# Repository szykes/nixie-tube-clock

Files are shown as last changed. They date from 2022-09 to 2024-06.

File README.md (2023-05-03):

# nixie-tube-clock

ezgif com-gif-maker-3





At first I declared my requirements for my ideal clock. Here are the requirements:
  * No touch working: there shall not be any button or something like that but the clock shall follow daylight saving time or it shall be set after a power outage.
  * Dust resistant: the dust shall not affect the visibility of clock and it shall not be on the PCB and parts.
  * Beautiful: The clock shall have maximum 2 dominant colors (PCB, parts and enclosure).
  
To implement "no touch working" I used a Wifi module to query the accureate time from my home server.
For "dust resistant" requirement I put the clock in a plastic enclosure to procect the core of clock.
"Beautiful" is implemented by selecting white PCB and mostly black parts.

## Docker

```
docker build -t time-server:v1.0 .
docker-compose up -d
```

## Hardware

### Measurements
  * Cathode voltage: 178 V
  * Cathode current: ~800 uA
  * Glim lamp current: ~250 uA
  * Total current: ~220 mA @ 12,2 V without WiFi.
  
### Known issues
  * RBG LED flahes at power-on. The gate of MOSFET of LEDs require a pull-down resistor.
  * PCB design of tube is wrong. The place drawing of tube is mirrored; therefore, digit 7 is digit 4 in real.

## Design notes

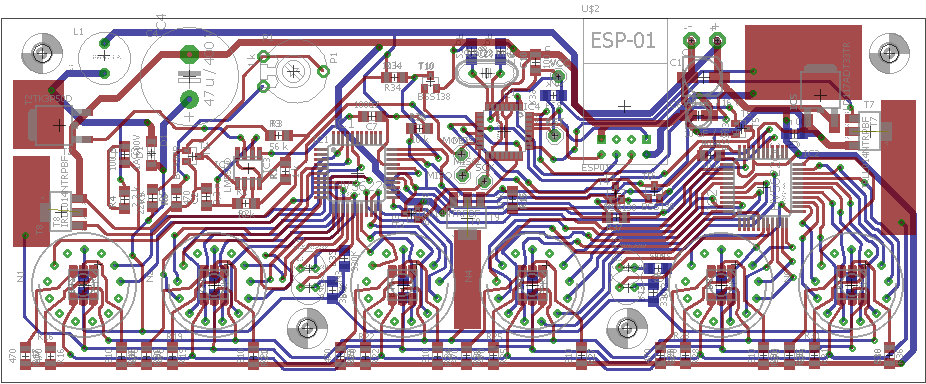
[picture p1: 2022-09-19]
eagle/nixie-tube-clock-pcb.png

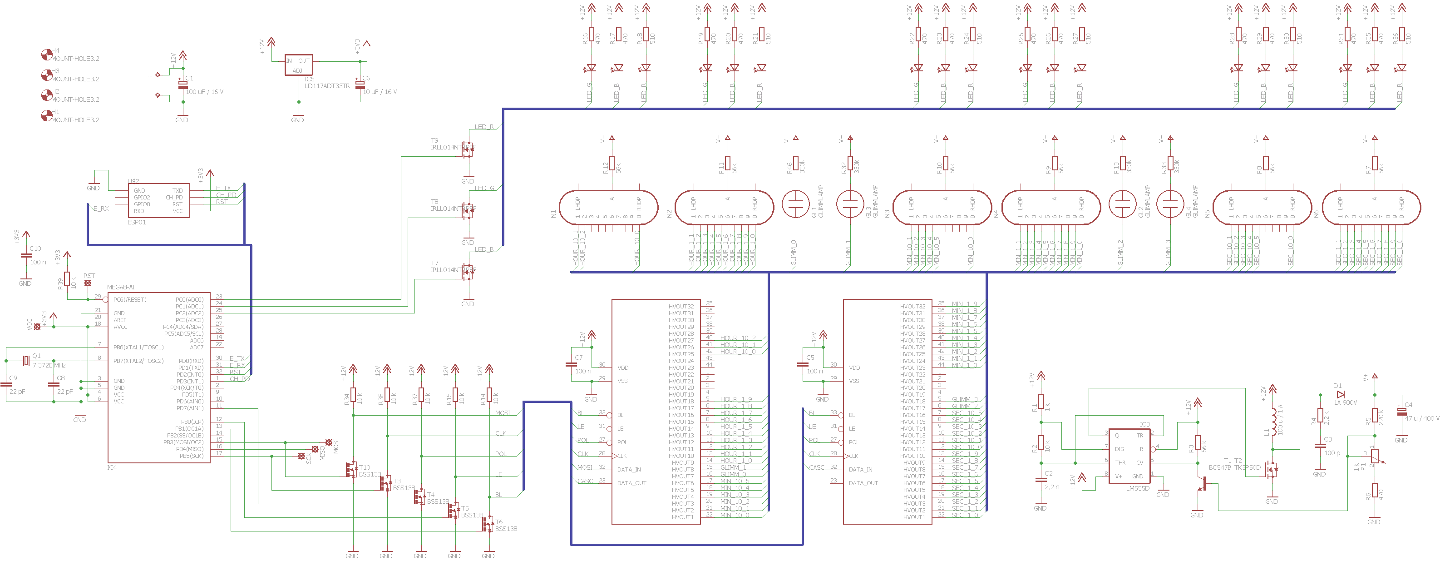
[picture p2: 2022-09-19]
eagle/nixie-tube-clock-sch.png

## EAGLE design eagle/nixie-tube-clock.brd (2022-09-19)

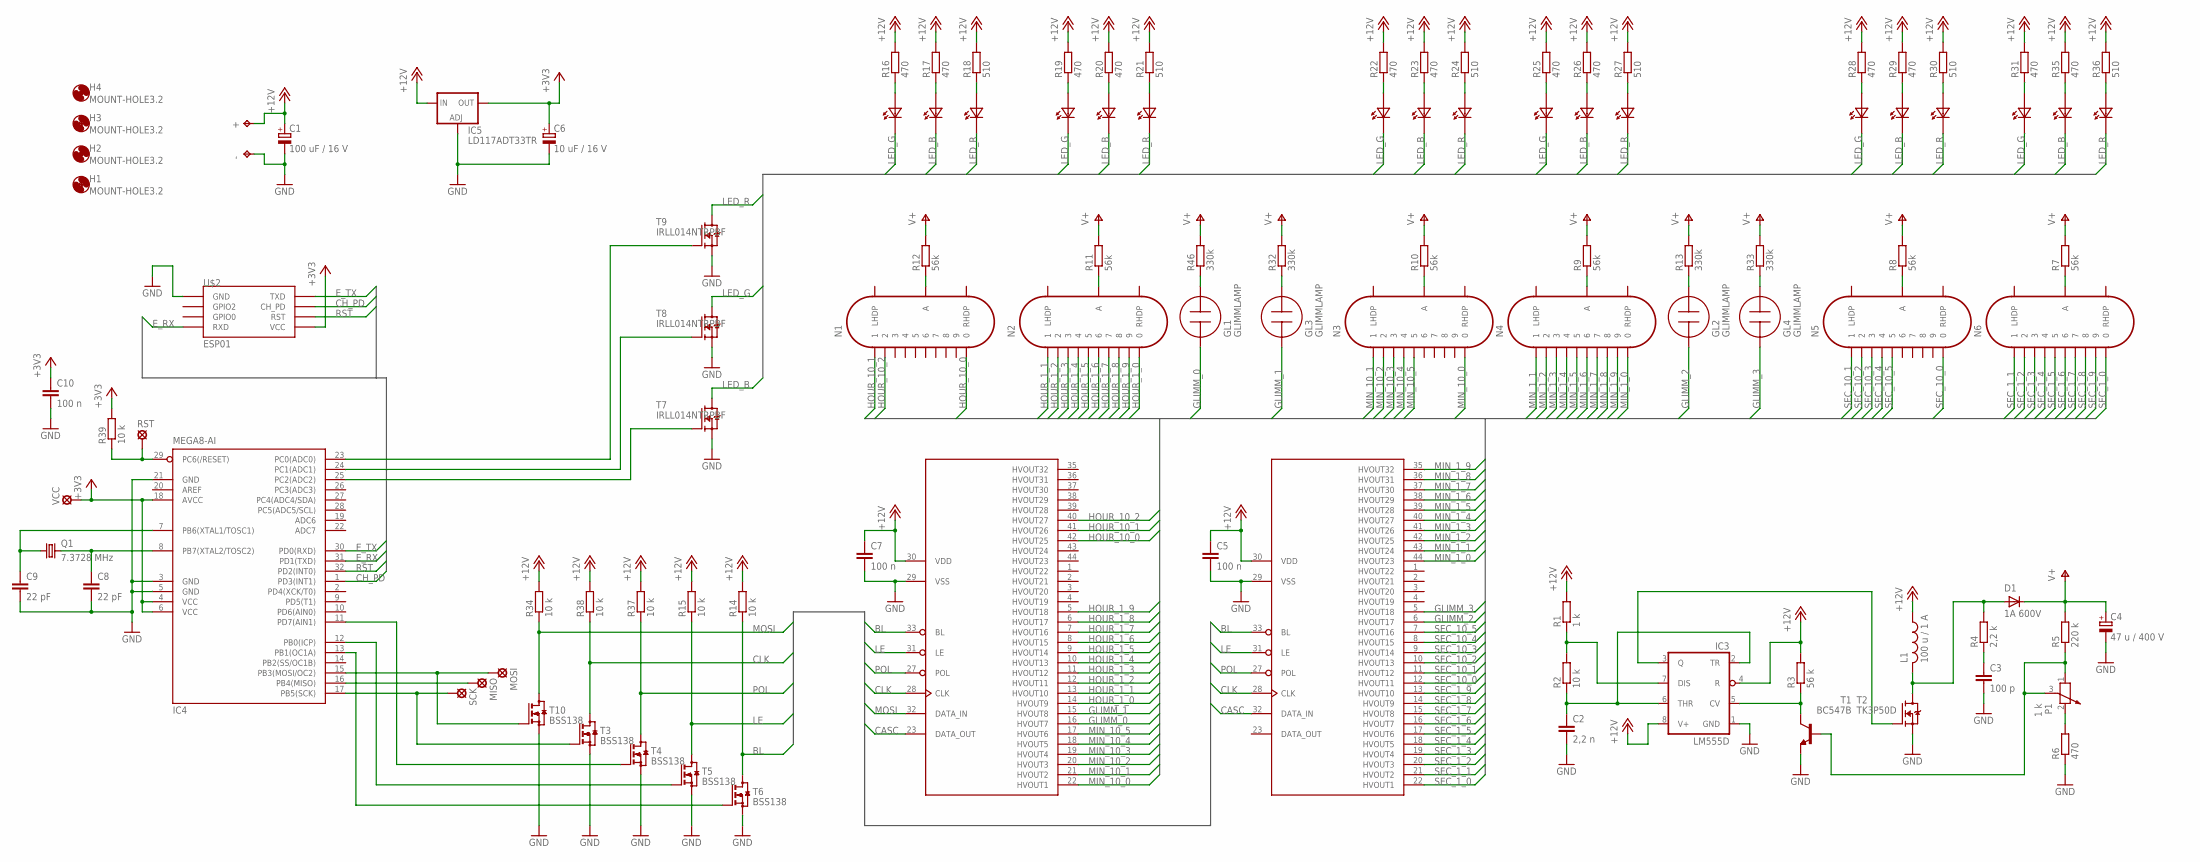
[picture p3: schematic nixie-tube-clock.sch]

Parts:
+: +; P1-17
-: -; P1-17
C1: 100 uF / 16 V; 153CLV-0605
C2: 2,2 n; C1206
C3: 100 p; C1206
C4: 47 u / 400 V; E7,5-16
C5, C7, C10: 100 n; C1206
C6: 10 uF / 16 V; 153CLV-0405
C8, C9: 22 pF; C1206
D1: 1A 600V; SMA-DO214AC
GL1, GL2, GL3, GL4: GLIMMLAMP
H1, H2, H3, H4: MOUNT-HOLE3.2; 3,2
IC1, IC2: HV5622QC; PQFP44
IC3: LM555D; SO08
IC4: MEGA8-AI; TQFP32-08
IC5: LD117ADT33TR; DPACK
L1: 100 u / 1 A; L_V_8.7X12_RM5.0
MISO: MISO; SE11
MOSI: MOSI; SE11
N1, N2, N3, N4, N5, N6: IN-14
P1: 1 k; PT-10
Q1: 7.3728 MHz; HC49/S
R1: 1 k; R1206
R2, R14, R15, R34, R37, R38, R39: 10 k; R1206
R3: 56 k; R1206
R4: 2,2 k; R1206
R5: 220 k; R1206
R6, R16, R17, R19, R20, R22, R23, R25, R26, R28, R29, R31, R35: 470; R1206
R7, R8, R9, R10, R11, R12: 56k; R1206
R13, R32, R33, R46: 330k; R1206
R18, R21, R24, R27, R30, R36: 510; R1206
RST: RST; SE11
SCK: SCK; SE11
T1: BC547B; SOT23-BEC
T2: TK3P50D; TO252
T3, T4, T5, T6, T10: BSS138; SOT23
T7, T8, T9: IRLL014NTRPBF; SOT223
U$1, U$3, U$4, U$5, U$6, U$7: OF-SMD5060RGB
U$2: ESP01
VCC: VCC; SE11

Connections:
+3V3: C6.+, C10.1, IC4.4 (VCC), IC4.6 (VCC), IC4.18 (AVCC), IC5.4 (OUT), R39.2, U$2.VCC, VCC.MP
+12V: +.TP, C1.+, C5.1, C7.1, IC1.30 (VDD), IC2.30 (VDD), IC3.4 (R), IC3.8 (V+), IC5.3 (IN), L1.P$1 (1), R1.2, R3.2, R14.2, R15.2, R16.2, R17.2, R18.2, R19.2, R20.2, R21.2, R22.2, R23.2, R24.2, R25.2, R26.2, R27.2, R28.2, R29.2, R30.2, R31.2, R34.2, R35.2, R36.2, R37.2, R38.2
BL: IC1.33 (BL), IC2.33 (BL), R14.1, T6.3 (D)
CASC: IC1.23 (DATA_OUT), IC2.32 (DATA_IN)
CH_PD: IC4.1 (PD3(INT1)), U$2.CH_PD
CLK: IC1.28 (CLK), IC2.28 (CLK), R38.1, T3.3 (D)
E_RX: IC4.31 (PD1(TXD)), U$2.RX (RXD)
E_TX: IC4.30 (PD0(RXD)), U$2.TX (TXD)
GLIMM_0: GL1.C, IC1.16 (HVOUT7)
GLIMM_1: GL3.C, IC1.15 (HVOUT8)
GLIMM_2: GL2.C, IC2.6 (HVOUT17)
GLIMM_3: GL4.C, IC2.5 (HVOUT18)
GND: -.TP, C1.-, C2.2, C3.2, C4.-, C5.2, C6.-, C7.2, C8.2, C9.2, C10.2, IC1.29 (VSS), IC2.29 (VSS), IC3.1 (GND), IC4.3 (GND), IC4.5 (GND), IC4.21 (GND), IC5.1 (ADJ), R6.1, T1.E, T2.2 (S), T3.2 (S), T4.2 (S), T5.2 (S), T6.2 (S), T7.3 (S), T8.3 (S), T9.3 (S), T10.2 (S), U$2.GND
HOUR_1_0: IC1.14 (HVOUT9), N2.0
HOUR_1_1: IC1.13 (HVOUT10), N2.1
HOUR_1_2: IC1.12 (HVOUT11), N2.2
HOUR_1_3: IC1.11 (HVOUT12), N2.3
HOUR_1_4: IC1.10 (HVOUT13), N2.4
HOUR_1_5: IC1.9 (HVOUT14), N2.5
HOUR_1_6: IC1.8 (HVOUT15), N2.6
HOUR_1_7: IC1.7 (HVOUT16), N2.7
HOUR_1_8: IC1.6 (HVOUT17), N2.8
HOUR_1_9: IC1.5 (HVOUT18), N2.9
HOUR_10_0: IC1.42 (HVOUT25), N1.0
HOUR_10_1: IC1.41 (HVOUT26), N1.1
HOUR_10_2: IC1.40 (HVOUT27), N1.2
LE: IC1.31 (LE), IC2.31 (LE), R15.1, T5.3 (D)
LED_B: T7.2 (D), T7.4 (D), U$1.B_CATH (CATH), U$3.B_CATH (CATH), U$4.B_CATH (CATH), U$5.B_CATH (CATH), U$6.B_CATH (CATH), U$7.B_CATH (CATH)
LED_D0: IC4.23 (PC0(ADC0)), T9.1 (G)
LED_D1: IC4.24 (PC1(ADC1)), T8.1 (G)
LED_D2: IC4.25 (PC2(ADC2)), T7.1 (G)
LED_G: T8.2 (D), T8.4 (D), U$1.G_CATH (CATH), U$3.G_CATH (CATH), U$4.G_CATH (CATH), U$5.G_CATH (CATH), U$6.G_CATH (CATH), U$7.G_CATH (CATH)
LED_R: T9.2 (D), T9.4 (D), U$1.R_CATH (CATH), U$3.R_CATH (CATH), U$4.R_CATH (CATH), U$5.R_CATH (CATH), U$6.R_CATH (CATH), U$7.R_CATH (CATH)
MIN_1_0: IC2.44 (HVOUT23), N4.0
MIN_1_1: IC2.43 (HVOUT24), N4.1
MIN_1_2: IC2.42 (HVOUT25), N4.2
MIN_1_3: IC2.41 (HVOUT26), N4.3
MIN_1_4: IC2.40 (HVOUT27), N4.4
MIN_1_5: IC2.39 (HVOUT28), N4.5
MIN_1_6: IC2.38 (HVOUT29), N4.6
MIN_1_7: IC2.37 (HVOUT30), N4.7
MIN_1_8: IC2.36 (HVOUT31), N4.8
MIN_1_9: IC2.35 (HVOUT32), N4.9
MIN_10_0: IC1.22 (HVOUT1), N3.0
MIN_10_1: IC1.21 (HVOUT2), N3.1
MIN_10_2: IC1.20 (HVOUT3), N3.2
MIN_10_3: IC1.19 (HVOUT4), N3.3
MIN_10_4: IC1.18 (HVOUT5), N3.4
MIN_10_5: IC1.17 (HVOUT6), N3.5
MOSI: IC1.32 (DATA_IN), R34.1, T10.3 (D)
unnamed: IC4.29 (PC6(/RESET)), R39.1, RST.MP
unnamed: IC3.7 (DIS), R1.1, R2.2
unnamed: IC3.5 (CV), R3.1, T1.C
unnamed: C2.1, IC3.2 (TR), IC3.6 (THR), R2.1
unnamed: IC3.3 (Q), T2.1 (G)
unnamed: D1.A, L1.P$2 (2), R4.2, T2.3 (D)
unnamed: P1.1, P1.3, R5.1, T1.B
unnamed: C3.1, R4.1
unnamed: P1.2, R6.2
unnamed: N1.A, R12.1
unnamed: N2.A, R11.1
unnamed: N3.A, R10.1
unnamed: N4.A, R9.1
unnamed: N5.A, R8.1
unnamed: N6.A, R7.1
unnamed: IC4.16 (PB4(MISO)), MISO.MP
unnamed: GL2.A, R13.1
unnamed: IC4.13 (PB1(OC1A)), T6.1 (G)
unnamed: R16.1, U$1.G_ANODE (ANODE)
unnamed: R17.1, U$1.B_ANODE (ANODE)
unnamed: R18.1, U$1.R_ANODE (ANODE)
unnamed: C8.1, IC4.8 (PB7(XTAL2/TOSC2)), Q1.2
unnamed: GL3.A, R32.1
unnamed: R19.1, U$3.G_ANODE (ANODE)
unnamed: R20.1, U$3.B_ANODE (ANODE)
unnamed: R21.1, U$3.R_ANODE (ANODE)
unnamed: IC4.12 (PB0(ICP)), T5.1 (G)
unnamed: GL4.A, R33.1
unnamed: C9.1, IC4.7 (PB6(XTAL1/TOSC1)), Q1.1
unnamed: R22.1, U$4.G_ANODE (ANODE)
unnamed: R23.1, U$4.B_ANODE (ANODE)
unnamed: R24.1, U$4.R_ANODE (ANODE)
unnamed: IC4.17 (PB5(SCK)), SCK.MP, T3.1 (G)
unnamed: R25.1, U$5.G_ANODE (ANODE)
unnamed: R26.1, U$5.B_ANODE (ANODE)
unnamed: R27.1, U$5.R_ANODE (ANODE)
unnamed: IC4.15 (PB3(MOSI/OC2)), MOSI.MP, T10.1 (G)
unnamed: IC4.11 (PD7(AIN1)), T4.1 (G)
unnamed: R28.1, U$6.G_ANODE (ANODE)
unnamed: R29.1, U$6.B_ANODE (ANODE)
unnamed: R30.1, U$6.R_ANODE (ANODE)
unnamed: R31.1, U$7.G_ANODE (ANODE)
unnamed: R35.1, U$7.B_ANODE (ANODE)
unnamed: R36.1, U$7.R_ANODE (ANODE)
unnamed: GL1.A, R46.1
POL: IC1.27 (POL), IC2.27 (POL), R37.1, T4.3 (D)
RST: IC4.32 (PD2(INT0)), U$2.RST
SEC_1_0: IC2.22 (HVOUT1), N6.0
SEC_1_1: IC2.21 (HVOUT2), N6.1
SEC_1_2: IC2.20 (HVOUT3), N6.2
SEC_1_3: IC2.19 (HVOUT4), N6.3
SEC_1_4: IC2.18 (HVOUT5), N6.4
SEC_1_5: IC2.17 (HVOUT6), N6.5
SEC_1_6: IC2.16 (HVOUT7), N6.6
SEC_1_7: IC2.15 (HVOUT8), N6.7
SEC_1_8: IC2.14 (HVOUT9), N6.8
SEC_1_9: IC2.13 (HVOUT10), N6.9
SEC_10_0: IC2.12 (HVOUT11), N5.0
SEC_10_1: IC2.11 (HVOUT12), N5.1
SEC_10_2: IC2.10 (HVOUT13), N5.2
SEC_10_3: IC2.9 (HVOUT14), N5.3
SEC_10_4: IC2.8 (HVOUT15), N5.4
SEC_10_5: IC2.7 (HVOUT16), N5.5
V+: C4.+, D1.K (C), R5.2, R7.2, R8.2, R9.2, R10.2, R11.2, R12.2, R13.2, R32.2, R33.2, R46.2

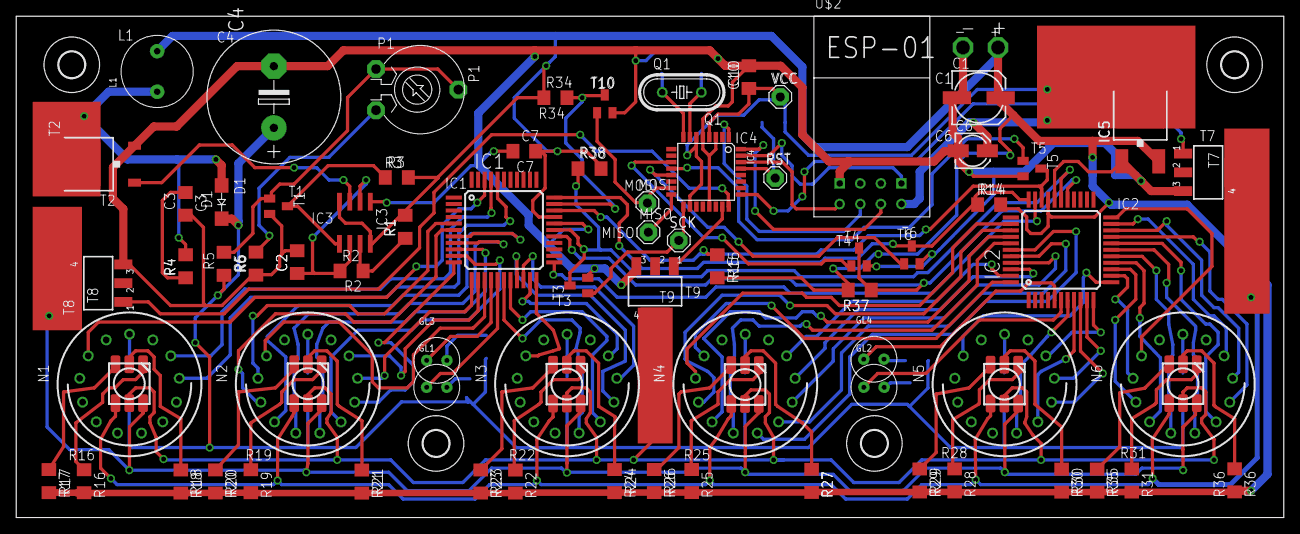
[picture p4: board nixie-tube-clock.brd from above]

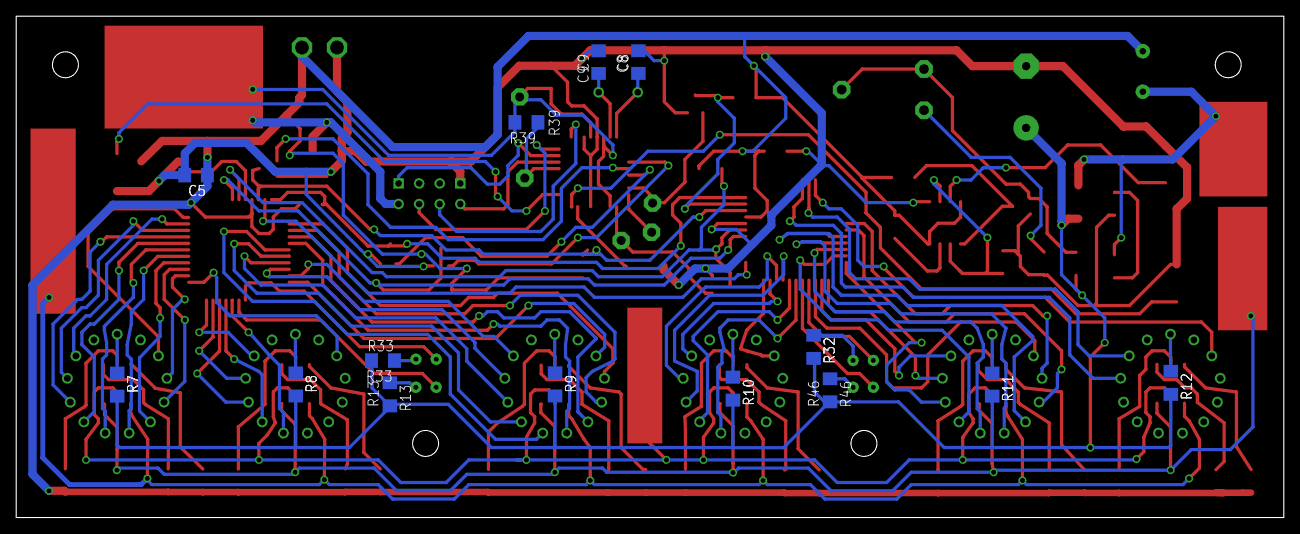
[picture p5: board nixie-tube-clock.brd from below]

Board: 2 copper layers, 156.4 x 61.9 mm, 97 parts (14 on the bottom side), 114 nets.

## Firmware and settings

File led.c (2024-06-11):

#include "led.h"

#include <stdbool.h>
#include <stdint.h>
#include <math.h>

#include "avr.h"
#include "wifi.h"
#include "clock.h"

#define MAX_CNT 240 // 28 800 Hz to 120 Hz

#define TIMER_INIT_CNT 0xFF

#define HHM_TO_SECS(hour_10, hour_1, min_10) ( \
    (hour_10) * 10 * 3600 +				\
    (hour_1) * 3600 +					\
    (min_10) * 10 * 60)

#define BRIGHT_PERIOD_IN_SECS ( \
  HHM_TO_SECS(MAX_HOUR_10, MAX_HOUR_1, MAX_MIN_10) - \
  HHM_TO_SECS(MIN_HOUR_10, MIN_HOUR_1, MIN_MIN_10))

#define SEVENTH_OF_BRIGHT_PERIOD_IN_SECS (BRIGHT_PERIOD_IN_SECS / (float) 7)

#define RATIO_MODIFIER 10

static volatile bool is_calculate = false;

static volatile uint8_t red_ratio = 0;
static volatile uint8_t green_ratio = 0;
static volatile uint8_t blue_ratio = 0;

static uint32_t get_time_in_secs(void) {
  const time_st *time = clock_get_time();
  uint32_t secs = 0;
  secs += time->hour_10 * 10ul * 3600ul;
  secs += time->hour_1 * 3600ul;
  secs += time->min_10 * 10ul * 60ul;
  secs += time->min_1 * 60ul;
  secs += time->sec_10 * 10ul;
  secs += time->sec_1;
  return secs;
}

static uint8_t increasing_ratio(uint32_t base) {
  uint16_t ratio = lrintf(base / (SEVENTH_OF_BRIGHT_PERIOD_IN_SECS / (float) (MAX_CNT + RATIO_MODIFIER)));
  return (ratio > MAX_CNT ? MAX_CNT : ratio);
}

static uint8_t decreasing_ratio(uint32_t base) {
  uint16_t ratio = lrintf(base / (SEVENTH_OF_BRIGHT_PERIOD_IN_SECS / (float) (MAX_CNT + RATIO_MODIFIER)));
  return MAX_CNT - (ratio > MAX_CNT ? MAX_CNT : ratio);
}

unsigned char led_isr(void) {
  static uint8_t cnt = 0;

  if (cnt >= MAX_CNT) {
    cnt = 0;
    clock_timer_interrupt();

    if (red_ratio != 0) {
      gpio_led_red_set();
    }
    if (green_ratio != 0) {
      gpio_led_green_set();
    }
    if (blue_ratio != 0) {
      gpio_led_blue_set();
    }
  }

  if (cnt >= red_ratio) {
    gpio_led_red_reset();
  }

  if (cnt >= green_ratio) {
    gpio_led_green_reset();
  }

  if (cnt >= blue_ratio) {
    gpio_led_blue_reset();
  }

  cnt++;

  return TIMER_INIT_CNT;
}

void led_init(void) {
  timer0_init(TIMER_INIT_CNT);
}

void led_timer_interrupt(void) {
  is_calculate = true;
}

void led_main(void) {
  if (is_calculate) {
    is_calculate = false;

    int64_t secs = get_time_in_secs() - HHM_TO_SECS(MIN_HOUR_10, MIN_HOUR_1, MIN_MIN_10);
    if (secs < 0) {
      secs = 0;
    }

    uint32_t mod = 0;
    if (secs >= 43208) {
      mod = 3;
    } else if (secs >= 28807) {
      mod = 2;
    } else if (secs >= 14403) {
      mod = 1;
    }

    uint32_t base = (secs + mod) % ((uint32_t) SEVENTH_OF_BRIGHT_PERIOD_IN_SECS + 1);

    if (secs > (7 * SEVENTH_OF_BRIGHT_PERIOD_IN_SECS) - 1) {
      red_ratio = 0;
      green_ratio = 0;
      blue_ratio = 0;
    } else if (secs > (6 * SEVENTH_OF_BRIGHT_PERIOD_IN_SECS) - 1) {
      red_ratio = 0;
      green_ratio = 0;
      blue_ratio = decreasing_ratio(base);
    } else if (secs > (5 * SEVENTH_OF_BRIGHT_PERIOD_IN_SECS)) {
      red_ratio = 0;
      green_ratio = decreasing_ratio(base);
      blue_ratio = MAX_CNT;
    } else if (secs > (4 * SEVENTH_OF_BRIGHT_PERIOD_IN_SECS) - 1) {
      red_ratio = 0;
      green_ratio = MAX_CNT;
      blue_ratio = increasing_ratio(base);
    } else if (secs > (3 * SEVENTH_OF_BRIGHT_PERIOD_IN_SECS)) {
      red_ratio = decreasing_ratio(base);
      green_ratio = MAX_CNT;
      blue_ratio = 0;
    } else if (secs > (2 * SEVENTH_OF_BRIGHT_PERIOD_IN_SECS) - 1) {
      red_ratio = MAX_CNT;
      green_ratio = increasing_ratio(base);
      blue_ratio = 0;
    } else if (secs > SEVENTH_OF_BRIGHT_PERIOD_IN_SECS) {
      red_ratio = MAX_CNT;
      green_ratio = 0;
      blue_ratio = decreasing_ratio(base);
    } else if (secs > 0) {
      red_ratio = increasing_ratio(base);
      green_ratio = 0;
      blue_ratio = increasing_ratio(base);
    } else {
      red_ratio = 0;
      green_ratio = 0;
      blue_ratio = 0;
    }
  }
}

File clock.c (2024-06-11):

#include "clock.h"

#include <stddef.h>
#include <string.h>
#include <stdbool.h>
#include <limits.h>

#include "avr.h"
#include "led.h"
#include "wifi.h"

/*
time_data[0]
7      | 6      | 5      | 4      | 3      | 2      | 1      | 0
M_1_2  | M_1_3  | M_1_4  | M_1_5  | M_1_6  | M_1_7  | M_1_8  | M_1_9

time_data[1]
7      | 6      | 5      | 4      | 3      | 2      | 1      | 0
M_1_0  | M_1_1  | NC     | NC     | NC     | NC     | GLIM_3 | GLIM_2

time_data[2]
7      | 6      | 5      | 4      | 3      | 2      | 1      | 0
S_10_5 | S_10_4 | S_10_3 | S_10_2 | S_10_0 | S_10_1 | S_1_2  | S_1_3

time_data[3]
7      | 6      | 5      | 4      | 3      | 2      | 1      | 0
S_1_4  | S_1_5  | S_1_6  | S_1_7  | S_1_8  | S_1_9  | S_1_0  | S_1_1

time_data[4]
7      | 6      | 5      | 4      | 3      | 2      | 1      | 0
NC     | NC     | NC     | NC     | NC     | H_10_2 | H_10_0 | H_10_1

time_data[5]
7      | 6      | 5      | 4      | 3      | 2      | 1      | 0
NC     | NC     | NC     | NC     | NC     | NC     | H_1_2  | H_1_3

time_data[6]
7      | 6      | 5      | 4      | 3      | 2      | 1      | 0
H_1_4  | H_1_5  | H_1_6  | H_1_7  | H_1_8  | H_1_9  | H_1_0  | H_1_1

time_data[7]
7      | 6      | 5      | 4      | 3      | 2      | 1      | 0
GLIM_1 | GLIM_0 | M_10_5 | M_10_4 | M_10_3 | M_10_2 | M_10_0 | M_10_1
 */


static time_st time_data;
static uint8_t time_raw_data[8];

static volatile bool increment_time = false;
static volatile bool resetting_glimm = false;

static void clear_time_raw_data(void) {
  memset(&time_raw_data, 0x00, sizeof(time_raw_data));
}

static void latch_enable(void) {
  gpio_latch_enable_reset();
  gpio_latch_enable_set();
}

static void reset_glimm(void) {
  time_raw_data[1] &= (uint8_t)~(3 << 0);
  time_raw_data[7] &= (uint8_t)~(3 << 6);
}

static void set_glimm(void) {
  time_raw_data[1] |= (3 << 0);
  time_raw_data[7] |= (3 << 6);
}

static void set_hour_10(uint8_t hour) {
  switch(hour) {
  case 0:
    time_raw_data[4] |= (1 << 1);
    break;
  case 1:
    time_raw_data[4] |= (1 << 0);
    break;
  case 2:
    time_raw_data[4] |= (1 << 2);
    break;
  default:
    break;
  }
}

static void set_hour_1(uint8_t hour) {
  switch(hour) {
  case 0:
    time_raw_data[6] |= (1 << 1);
    break;
  case 1:
    time_raw_data[6] |= (1 << 0);
    break;
  case 2:
    time_raw_data[5] |= (1 << 1);
    break;
  case 3:
    time_raw_data[5] |= (1 << 0);
    break;
  case 4:
    time_raw_data[6] |= (1 << 7);
    break;
  case 5:
    time_raw_data[6] |= (1 << 6);
    break;
  case 6:
    time_raw_data[6] |= (1 << 5);
    break;
  case 7:
    time_raw_data[6] |= (1 << 4);
    break;
  case 8:
    time_raw_data[6] |= (1 << 3);
    break;
  case 9:
    time_raw_data[6] |= (1 << 2);
    break;
  default:
    break;
  }
}

static void set_min_10(uint8_t min) {
  switch(min) {
  case 0:
    time_raw_data[7] |= (1 << 1);
    break;
  case 1:
    time_raw_data[7] |= (1 << 0);
    break;
  case 2:
  case 3:
  case 4:
  case 5:
    time_raw_data[7] |= (1 << min);
    break;
  default:
    break;
  }
}

static void set_min_1(uint8_t min) {
  switch(min) {
  case 0:
    time_raw_data[1] |= (1 << 7);
    break;
  case 1:
    time_raw_data[1] |= (1 << 6);
    break;
  case 2:
  case 3:
  case 4:
  case 5:
  case 6:
  case 7:
  case 8:
  case 9:
    time_raw_data[0] |= (1 << (9 - min));
    break;
  default:
    break;
  }
}

static void set_sec_10(uint8_t sec) {
  switch(sec) {
  case 0:
    time_raw_data[2] |= (1 << 3);
    break;
  case 1:
    time_raw_data[2] |= (1 << 2);
    break;
  case 2:
  case 3:
  case 4:
  case 5:
    time_raw_data[2] |= (1 << (sec + 2));
    break;
  default:
    break;
  }
}

static void set_sec_1(uint8_t sec) {
  switch(sec) {
  case 0:
    time_raw_data[3] |= (1 << 1);
    break;
  case 1:
    time_raw_data[3] |= (1 << 0);
    break;
  case 2:
    time_raw_data[2] |= (1 << 1);
    break;
  case 3:
    time_raw_data[2] |= (1 << 0);
    break;
  case 4:
    time_raw_data[3] |= (1 << 7);
    break;
  case 5:
    time_raw_data[3] |= (1 << 6);
    break;
  case 6:
    time_raw_data[3] |= (1 << 5);
    break;
  case 7:
    time_raw_data[3] |= (1 << 4);
    break;
  case 8:
    time_raw_data[3] |= (1 << 3);
    break;
  case 9:
    time_raw_data[3] |= (1 << 2);
    break;
  default:
    break;
  }
}

static bool is_dark_period(void) {
  return ((time_data.hour_10 == MAX_HOUR_10) && (time_data.hour_1 > MAX_HOUR_1)) ||
    ((time_data.hour_10 == MAX_HOUR_10) && (time_data.hour_1 == MAX_HOUR_1) && (time_data.min_10 >= MAX_MIN_10)) ||
    ((time_data.hour_10 == MIN_HOUR_10) && (time_data.hour_1 < MIN_HOUR_1)) ||
    ((time_data.hour_10 == MIN_HOUR_10) && (time_data.hour_1 == MIN_HOUR_1) && (time_data.min_10 < MIN_MIN_10));
}

static void calculate_time(void) {
  clear_time_raw_data();

  time_data.sec_1++;

  if (time_data.sec_1 >= 10) {
    time_data.sec_1 = 0;
    time_data.sec_10++;
  }

  if (time_data.sec_10 >= 6) {
    time_data.sec_10 = 0;
    time_data.min_1++;
  }

  if (time_data.min_1 >= 10) {
    time_data.min_1 = 0;
    time_data.min_10++;
  }

  if (time_data.min_10 >= 6) {
    time_data.min_10 = 0;
    time_data.hour_1++;
  }

  if (time_data.hour_1 >= 10) {
    time_data.hour_1 = 0;
    time_data.hour_10++;
  }

  if ((time_data.hour_10 >= 2) && (time_data.hour_1 >= 4)) {
    time_data.hour_10 = 0;
    time_data.hour_1 = 0;
  }

  set_hour_10(time_data.hour_10);
  set_hour_1(time_data.hour_1);
  set_min_10(time_data.min_10);
  set_min_1(time_data.min_1);
  set_sec_10(time_data.sec_10);
  set_sec_1(time_data.sec_1);

  if (((time_data.hour_10 == 0 && time_data.hour_1 == 5 && time_data.min_10 == 2) ||
       !is_dark_period()) &&
      time_data.hour_10 != 2 &&
      (time_data.min_1 == 0 && time_data.sec_10 == 0 && time_data.sec_1 == 0)) {
    wifi_query_timer();
  }
}

static void turn_off_display(void) {
  if (is_dark_period()) {
    gpio_polarity_reset();
    gpio_blanking_set();
  } else {
    gpio_polarity_set();
    gpio_blanking_reset();
  }
}

static void transmit_bits(size_t idx) {
  for (int8_t i = CHAR_BIT - 1; i >= 0; i--) {
    if (time_raw_data[idx] & (1 << i)) {
      gpio_data_set();
    } else {
      gpio_data_reset();
    }
    gpio_do_clk_cyc();
  }
}

static void send_spi_time_data(void) {
  // SPI does not work well, the pins are floating.
  // I implemented myself.
  for (size_t i = 0; i < sizeof(time_raw_data); i++) {
    transmit_bits(i);
  }
  latch_enable();
}

void clock_init(void) {
  gpio_polarity_set();
  gpio_latch_enable_set();

  time_data.hour_10 = 1;
  time_data.hour_1 = 9;
  time_data.min_10 = 4;
  time_data.min_1 = 9;
  time_data.sec_10 = 4;
  time_data.sec_1 = 8;

  calculate_time();

  send_spi_time_data();
}

void clock_timer_interrupt(void) {
  static uint8_t cnt = 0;

  cnt++;

  if (cnt >= kLedOneSecCnt) {
    cnt = 0;
    increment_time = true;
    wifi_timer_interrupt();
    led_timer_interrupt();
  }

  if (cnt == kLedOneSecCnt / 2) {
    resetting_glimm = true;
  }
}
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

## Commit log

2022-05-23 Alfa version of schematic
    [nixie-tube-clock.sch]
2022-05-24 Alfa v2 version of schematic
    [nixie-tube-clock.sch]
2022-06-01 First version of led
2022-06-02 Added watchdog timer
2022-06-02 Small adjustments in led package
2022-06-08 Beta version of schematic
    [nixie-tube-clock.sch]
2022-06-09 Small update on sch + added PCB
    [nixie-tube-clock.brd, nixie-tube-clock.sch]
2022-06-17 Add sending and receivin code of UART
2022-06-17 Fixing used F_OSC in the code
    [clock.c, led.c, wifi.c]
2022-06-17 Added at command response timer
2022-08-02 Beta version of PCB
    [nixie-tube-clock.brd]
2022-08-02 Pre-release version of PCB
    [nixie-tube-clock.brd, nixie-tube-clock.sch]
2022-08-03 Finalize PCB
    [nixie-tube-clock.brd]
2022-08-19 Replaced RGB LED + Gerber files
    [nixie-tube-clock.brd, nixie-tube-clock.sch]
2022-09-09 Fixing GND issue at IC5 + relocation of C4, P1 and L1
    [nixie-tube-clock.brd]
2022-09-18 Some reworks around the HV5622 ans ESP
    [nixie-tube-clock.brd, nixie-tube-clock.sch]
2022-09-19 Final adjustments
    [nixie-tube-clock.brd, nixie-tube-clock.sch]
2022-10-30 Sending data via "SPI" but the data itself is not correct yet
    [clock.c]
2022-10-30 Fix blue led gpio
2022-10-30 Handling LED ratio correctly + some minor fixes
    [led.c, wifi.c]
2022-10-30 Fix the misrouted tubes
    [clock.c, led.c]
2022-11-01 Enable global interrupt at first
2022-11-01 Provide LED ratio info from server
2022-11-01 Gather LED ratio from server
2022-11-03 Fixed error handling of ESP + regular time querry
    [clock.c, led.c, wifi.c]
2022-11-04 Align LED ratio slowly
2022-11-08 Fix dark period if statement
    [clock.c]
2022-11-08 Set wanted blue LED ratio
2022-11-14 Fix dark period -> finally it works as exprected!
    [clock.c]
2022-11-14 Replace define with const int
    [wifi.c]
2022-11-14 Use RBG LED
2022-11-14 Fix reset pins of RBG LED
    [led.c]
2022-11-14 Zero ratios of RGB LED
2022-12-11 Fix time handling at 23:59:59
    [clock.c]
2024-06-11 Refactor everything (#1)
    * updated Dockerfile + server binary
    * add gh workflow verify for server side
    * add bulding and pushing docker image GH workflow
    * add GH workflow for verifying clock source
    * move gpio funcs
    * rework main file
    * rework wifi
    * rework led
    * remove unused include
    * add test framework
    * cover wifi.c with test
    * refactor mock fw
    * cover led.c with tests
    * cover clock.c with tests
    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
    [avr.c, avr_mock.c, clock.c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]
